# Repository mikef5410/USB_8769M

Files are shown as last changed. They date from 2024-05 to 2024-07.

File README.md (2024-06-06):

## USB_8769M 

USB control of Keysight 50GHz SP6T.

Related projects: [my USB Dual SPDT project](https://github.com/mikef5410/USB_SPDT)  and  [the software for these projects](https://github.com/mikef5410/USB_Attenuator_Switch_Stacklight)

# Project setup

The software is included here as a git submodule. After cloning, do a
`git submodule init` followed by `git submodule update --recursive`

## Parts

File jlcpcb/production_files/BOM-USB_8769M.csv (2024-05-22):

Comment | Designator | Footprint | LCSC
4.7u | C17,C5,C7 | C_0402_1005Metric_Pad0.74x0.62mm_HandSolder | C106859
LP2985-3.3 | U2 | SOT-23-5 | C109382
Conn_02x07_Odd_Even | J3 | IDC-Header_2x07_P2.54mm_Vertical | C11215
MMZ1608Y102B | FB1 | C_0603_1608Metric_Pad1.08x0.95mm_HandSolder | C114771
13.3k | R5 | R_0402_1005Metric_Pad0.72x0.64mm_HandSolder | C122547
22uF | C19 | C_1206_3216Metric_Pad1.33x1.80mm_HandSolder | C12891
USB_B_Micro | J1 | USB_Micro-B_Amphenol_10118193-0001LF_Horizontal | C132562
1u | C1,C14,C20,C21,C4 | C_0603_1608Metric_Pad1.08x0.95mm_HandSolder | C15849
220p | C2 | C_0402_1005Metric_Pad0.74x0.62mm_HandSolder | C1603
30pF | C15,C16 | C_0402_1005Metric_Pad0.74x0.62mm_HandSolder | C1658
10u | L1 | L_Changjiang_FNR4030S | C167879
0 | R1,R6 | R_0402_1005Metric_Pad0.72x0.64mm_HandSolder | C17168
4.7u | C3 | C_0805_2012Metric_Pad1.18x1.45mm_HandSolder | C1779
100 | R11,R13,R14,R15,R16,R9 | R_0402_1005Metric_Pad0.72x0.64mm_HandSolder | C25076
10k | R10,R12,R7,R8 | R_0402_1005Metric_Pad0.72x0.64mm_HandSolder | C25744
118k | R4 | R_0402_1005Metric_Pad0.72x0.64mm_HandSolder | C25748
SW_Push | SW1,SW2 | SW_Tactile_SPST_NO_Straight_CK_PTS636Sx25SMTRLFS | C2800965
PRTR5V0U2X | D2 | SOT-143 | C2827688
LM27313XMF | U1 | SOT-23-5 | C341750
GRN | D4 | LED_0603_1608Metric_Pad1.05x0.95mm_HandSolder | C434423
93LC66AT-IOT | U4 | SOT-23-6 | C511344
0.1u | C10,C11,C12,C13,C18,C6,C8,C9 | C_0402_1005Metric_Pad0.74x0.62mm_HandSolder | C5142567
16M 20pF 3225 | Y1 | Crystal_SMD_3225-4Pin_3.2x2.5mm_HandSoldering | C524727
ULN2003ADR | U5,U6 | SOIC-16_4.55x10.3mm_P1.27mm | C7512
RED | D3,D5,D6,D7 | LED_0603_1608Metric_Pad1.05x0.95mm_HandSolder | C84263
SS34 | D1 | D_SMA | C8678
STM32F411RETx | U3 | LQFP-64_10x10mm_P0.5mm | C94355

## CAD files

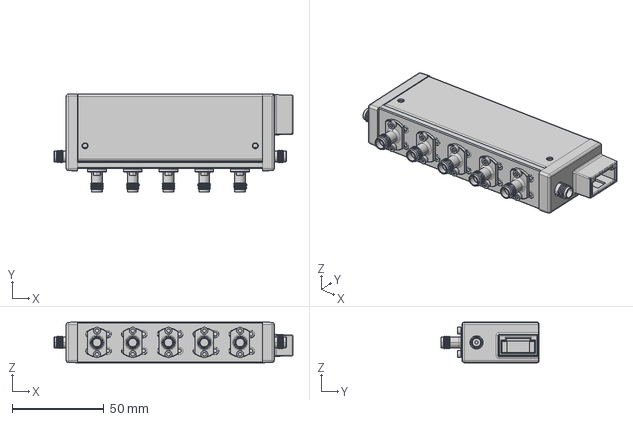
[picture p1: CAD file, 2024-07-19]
8769M.STP
130.2 x 53.6 x 22.3 mm

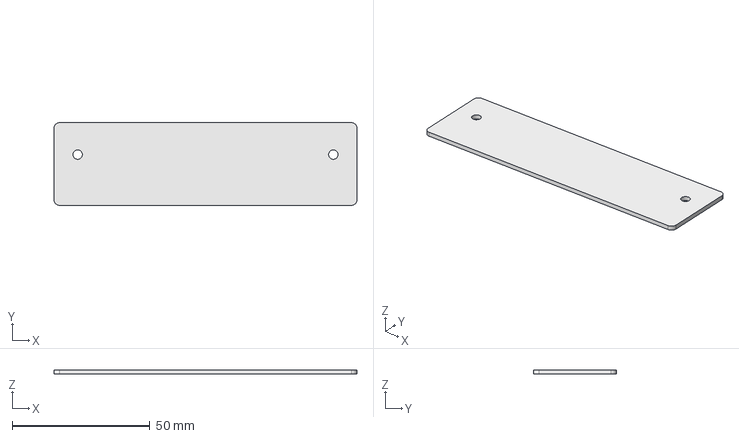
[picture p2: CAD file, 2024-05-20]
pcb_blank.FCStd
110.0 x 30.0 x 1.60 mm

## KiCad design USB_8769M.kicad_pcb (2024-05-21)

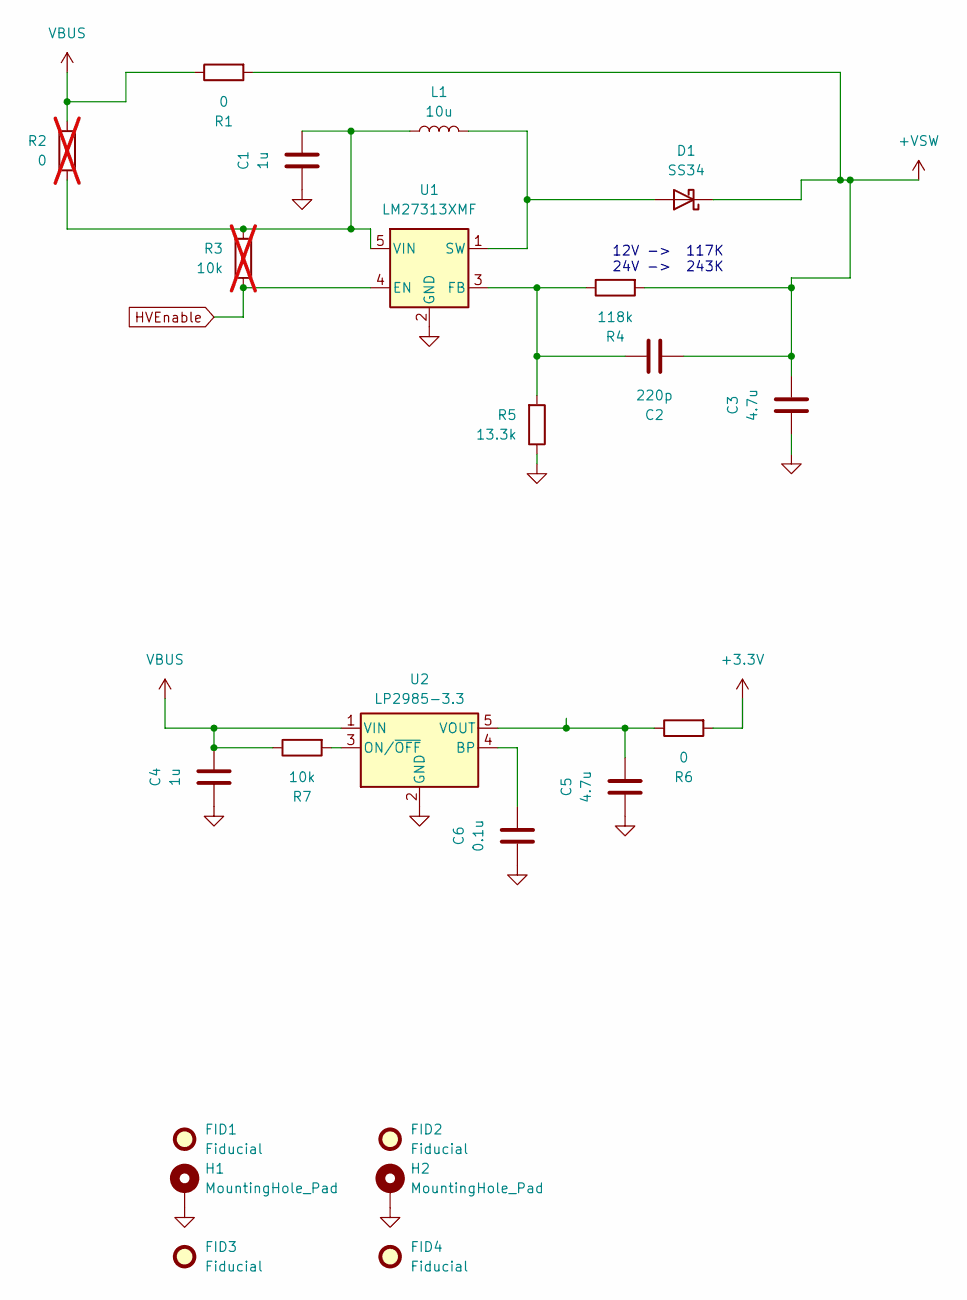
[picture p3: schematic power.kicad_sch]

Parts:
C1, C4: 1u; C_0603_1608Metric_Pad1.08x0.95mm_HandSolder; LCSC C15849
C2: 220p; C_0402_1005Metric_Pad0.74x0.62mm_HandSolder; LCSC C1603
C3: 4.7u; C_0805_2012Metric_Pad1.18x1.45mm_HandSolder; LCSC C1779
C5: 4.7u; C_0402_1005Metric_Pad0.74x0.62mm_HandSolder; LCSC C106859
C6: 0.1u; C_0402_1005Metric_Pad0.74x0.62mm_HandSolder; LCSC C5142567
D1: SS34; D_SMA; LCSC C8678
FID1, FID2, FID3, FID4: Fiducial; Fiducial_1mm_Mask3mm
H1, H2: MountingHole_Pad; MountingHole_3.2mm_M3_DIN965_Pad_TopBottom
L1: 10u; L_Changjiang_FNR4030S; LCSC C167879
R1, R6: 0; R_0402_1005Metric_Pad0.72x0.64mm_HandSolder; LCSC C17168
R2: 0; R_0402_1005Metric_Pad0.72x0.64mm_HandSolder; LCSC C17168; not fitted
R3: 10k; R_0402_1005Metric_Pad0.72x0.64mm_HandSolder; LCSC C25744; not fitted
R4: 118k; R_0402_1005Metric_Pad0.72x0.64mm_HandSolder; LCSC C25748
R5: 13.3k; R_0402_1005Metric_Pad0.72x0.64mm_HandSolder; LCSC C122547
R7: 10k; R_0402_1005Metric_Pad0.72x0.64mm_HandSolder; LCSC C25744
U1: LM27313XMF; SOT-23-5; LCSC C341750
U2: LP2985-3.3; SOT-23-5; LCSC C109382

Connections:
+3.3V: R6.2; also elsewhere on the board
+VSW: C2.1, C3.2, D1.1 (K), R1.2, R4.2; also elsewhere on the board
GND: C1.1, C3.1, C4.1, C5.1, C6.1, H1.1, H2.1, R5.1, U1.2 (GND), U2.2 (GND); also elsewhere on the board
HVEnable: R3.1, U1.4 (EN); also elsewhere on the board
unnamed: D1.2 (A), L1.2, U1.1 (SW)
unnamed: C2.2, R4.1, R5.2, U1.3 (FB)
unnamed: C1.2, L1.1, R2.1, R3.2, U1.5 (VIN)
unnamed: C6.2, U2.4 (BP)
unnamed: R7.2, U2.3 (ON/~OFF)
unnamed: C5.2, R6.1, U2.5 (VOUT)
VBUS: C4.2, R1.1, R2.2, R7.1, U2.1 (VIN); also elsewhere on the board

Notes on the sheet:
12V -> 117K 24V -> 243K

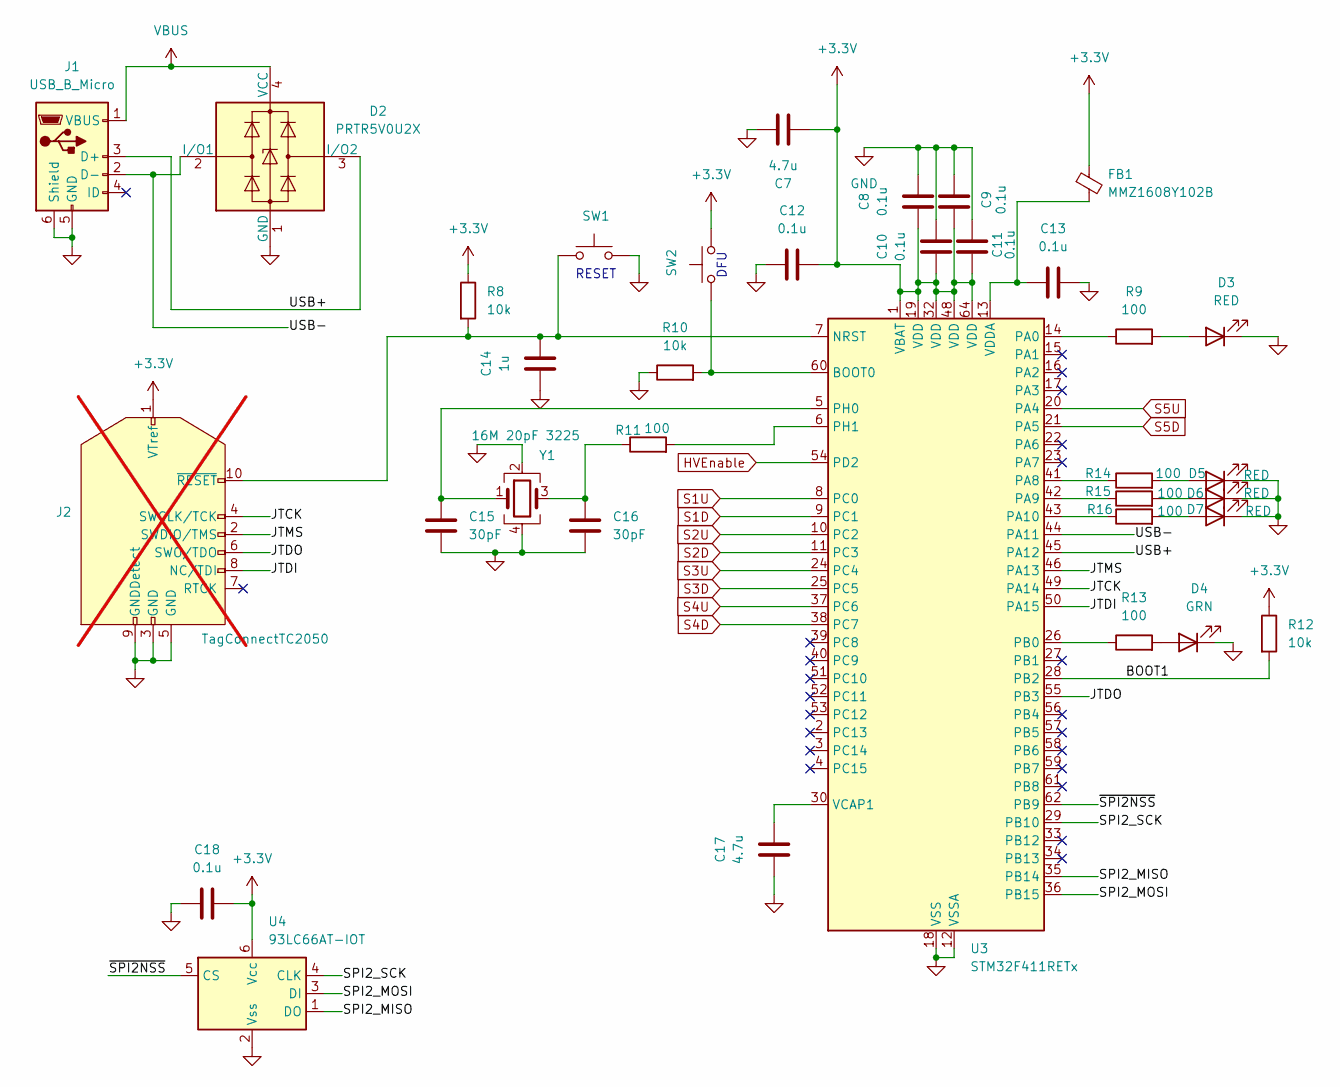
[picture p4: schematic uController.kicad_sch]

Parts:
C7, C17: 4.7u; C_0402_1005Metric_Pad0.74x0.62mm_HandSolder; LCSC C106859
C8, C9, C10, C11, C12, C13, C18: 0.1u; C_0402_1005Metric_Pad0.74x0.62mm_HandSolder; LCSC C5142567
C14: 1u; C_0603_1608Metric_Pad1.08x0.95mm_HandSolder; LCSC C15849
C15, C16: 30pF; C_0402_1005Metric_Pad0.74x0.62mm_HandSolder; LCSC C1658
D2: PRTR5V0U2X; SOT-143; LCSC C2827688
D3, D5, D6, D7: RED; LED_0603_1608Metric_Pad1.05x0.95mm_HandSolder; LCSC C84263
D4: GRN; LED_0603_1608Metric_Pad1.05x0.95mm_HandSolder; LCSC C434423
FB1: MMZ1608Y102B; C_0603_1608Metric_Pad1.08x0.95mm_HandSolder; LCSC C114771
J1: USB_B_Micro; USB_Micro-B_Amphenol_10118193-0001LF_Horizontal; LCSC C132562
J2: TagConnectTC2050; Tag-Connect_TC2050-IDC-FP_2x05_P1.27mm_Vertical; not fitted
R8, R10, R12: 10k; R_0402_1005Metric_Pad0.72x0.64mm_HandSolder; LCSC C25744
R9, R11, R13, R14, R15, R16: 100; R_0402_1005Metric_Pad0.72x0.64mm_HandSolder; LCSC C25076
SW1, SW2: SW_Push; SW_Tactile_SPST_NO_Straight_CK_PTS636Sx25SMTRLFS; LCSC C2800965
U3: STM32F411RETx; LQFP-64_10x10mm_P0.5mm; LCSC C94355
U4: 93LC66AT-IOT; SOT-23-6; LCSC C511344
Y1: 16M 20pF 3225; Crystal_SMD_3225-4Pin_3.2x2.5mm_HandSoldering; MPN 7U16000E20UCG; LCSC C524727

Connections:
+3.3V: C7.1, C8.1, C9.2, C10.1, C11.1, C12.2, C18.2, FB1.1, J2.1 (VTref), R8.1, R12.1, SW2.2, U3.1 (VBAT), U3.19 (VDD), U3.32 (VDD), U3.48 (VDD), U3.64 (VDD), U4.6 (Vcc); also elsewhere on the board
/uController/BOOT1: R12.2, U3.28 (PB2)
/uController/JTCK: J2.4 (SWCLK/TCK), U3.49 (PA14)
/uController/JTDI: J2.8 (NC/TDI), U3.50 (PA15)
/uController/JTDO: J2.6 (SWO/TDO), U3.55 (PB3)
/uController/JTMS: J2.2 (SWDIO/TMS), U3.46 (PA13)
/uController/SPI2_MISO: U3.35 (PB14), U4.1 (DO)
/uController/SPI2_MOSI: U3.36 (PB15), U4.3 (DI)
/uController/SPI2_SCK: U3.29 (PB10), U4.4 (CLK)
/uController/USB+: D2.3 (I/O2), J1.3 (D+), U3.45 (PA12)
/uController/USB-: D2.2 (I/O1), J1.2 (D-), U3.44 (PA11)
/uController/~SPI2NSS: U3.62 (PB9), U4.5 (CS)
GND: C7.2, C8.2, C9.1, C10.2, C11.2, C12.1, C13.2, C14.1, C15.2, C16.2, C17.1, C18.1, D2.1 (GND), D3.1 (K), D4.1 (K), D5.1 (K), D6.1 (K), D7.1 (K), J1.5 (GND), J1.6 (Shield), J2.3 (GND), J2.5 (GND), J2.9 (GNDDetect), R10.1, SW1.2, U3.12 (VSSA), U3.18 (VSS), U3.31 (VSS), U3.47 (VSS), U3.63 (VSS), U4.2 (Vss), Y1.2, Y1.4; also elsewhere on the board
HVEnable: U3.54 (PD2); also elsewhere on the board
unnamed: C16.1, R11.1, Y1.3
unnamed: D3.2 (A), R9.2
unnamed: D4.2 (A), R13.2
unnamed: D5.2 (A), R14.2
unnamed: D6.2 (A), R15.2
unnamed: D7.2 (A), R16.2
unnamed: C14.2, J2.10 (~RESET), R8.2, SW1.1, U3.7 (NRST)
unnamed: R10.2, SW2.1, U3.60 (BOOT0)
unnamed: R9.1, U3.14 (PA0)
unnamed: R14.1, U3.41 (PA8)
unnamed: R15.1, U3.42 (PA9)
unnamed: R16.1, U3.43 (PA10)
unnamed: R13.1, U3.26 (PB0)
unnamed: C15.1, U3.5 (PH0), Y1.1
unnamed: R11.2, U3.6 (PH1)
unnamed: C17.2, U3.30 (VCAP1)
unnamed: C13.1, FB1.2, U3.13 (VDDA)
S1D: U3.9 (PC1); also elsewhere on the board
S1U: U3.8 (PC0); also elsewhere on the board
S2D: U3.11 (PC3); also elsewhere on the board
S2U: U3.10 (PC2); also elsewhere on the board
S3D: U3.25 (PC5); also elsewhere on the board
S3U: U3.24 (PC4); also elsewhere on the board
S4D: U3.38 (PC7); also elsewhere on the board
S4U: U3.37 (PC6); also elsewhere on the board
S5D: U3.21 (PA5); also elsewhere on the board
S5U: U3.20 (PA4); also elsewhere on the board
VBUS: D2.4 (VCC), J1.1 (VBUS); also elsewhere on the board

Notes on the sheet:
RESET
DFU

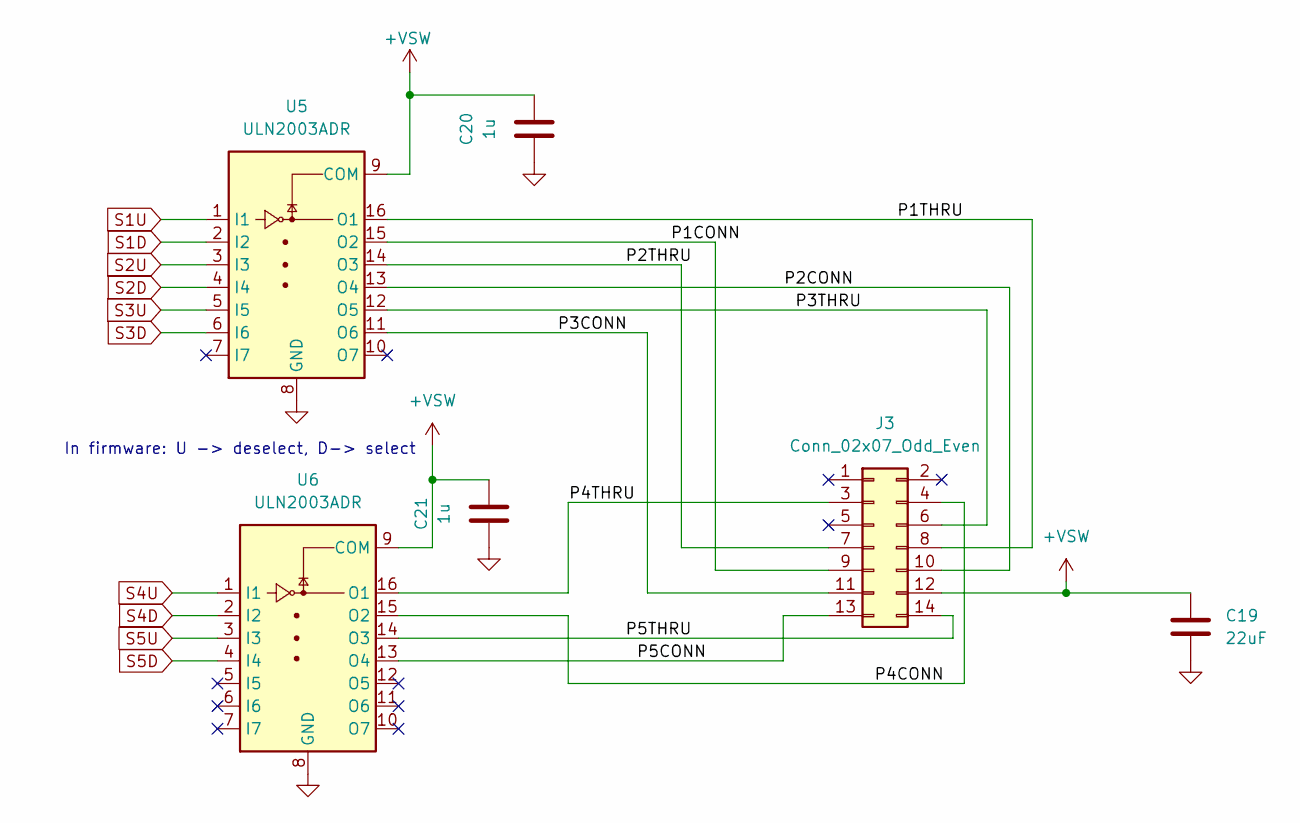
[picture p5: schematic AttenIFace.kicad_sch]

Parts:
C19: 22uF; C_1206_3216Metric_Pad1.33x1.80mm_HandSolder; LCSC C12891
C20, C21: 1u; C_0603_1608Metric_Pad1.08x0.95mm_HandSolder; LCSC C15849
J3: Conn_02x07_Odd_Even; IDC-Header_2x07_P2.54mm_Vertical; LCSC C11215
U5, U6: ULN2003ADR; SOIC-16_4.55x10.3mm_P1.27mm; LCSC C7512

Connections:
+VSW: C19.1, C20.2, C21.2, J3.12, U5.9 (COM), U6.9 (COM); also elsewhere on the board
/AttenIFace/P1CONN: J3.9, U5.15 (O2)
/AttenIFace/P1THRU: J3.8, U5.16 (O1)
/AttenIFace/P2CONN: J3.10, U5.13 (O4)
/AttenIFace/P2THRU: J3.7, U5.14 (O3)
/AttenIFace/P3CONN: J3.11, U5.11 (O6)
/AttenIFace/P3THRU: J3.6, U5.12 (O5)
/AttenIFace/P4CONN: J3.4, U6.15 (O2)
/AttenIFace/P4THRU: J3.3, U6.16 (O1)
/AttenIFace/P5CONN: J3.13, U6.13 (O4)
/AttenIFace/P5THRU: J3.14, U6.14 (O3)
GND: C19.2, C20.1, C21.1, U5.8 (GND), U6.8 (GND); also elsewhere on the board
S1D: U5.2 (I2); also elsewhere on the board
S1U: U5.1 (I1); also elsewhere on the board
S2D: U5.4 (I4); also elsewhere on the board
S2U: U5.3 (I3); also elsewhere on the board
S3D: U5.6 (I6); also elsewhere on the board
S3U: U5.5 (I5); also elsewhere on the board
S4D: U6.2 (I2); also elsewhere on the board
S4U: U6.1 (I1); also elsewhere on the board
S5D: U6.4 (I4); also elsewhere on the board
S5U: U6.3 (I3); also elsewhere on the board

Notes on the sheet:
In firmware: U -> deselect, D-> select

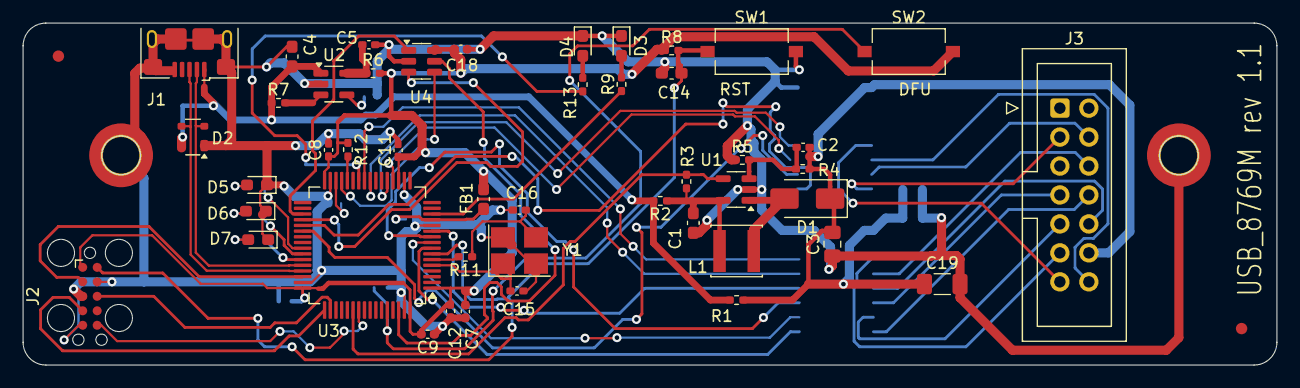
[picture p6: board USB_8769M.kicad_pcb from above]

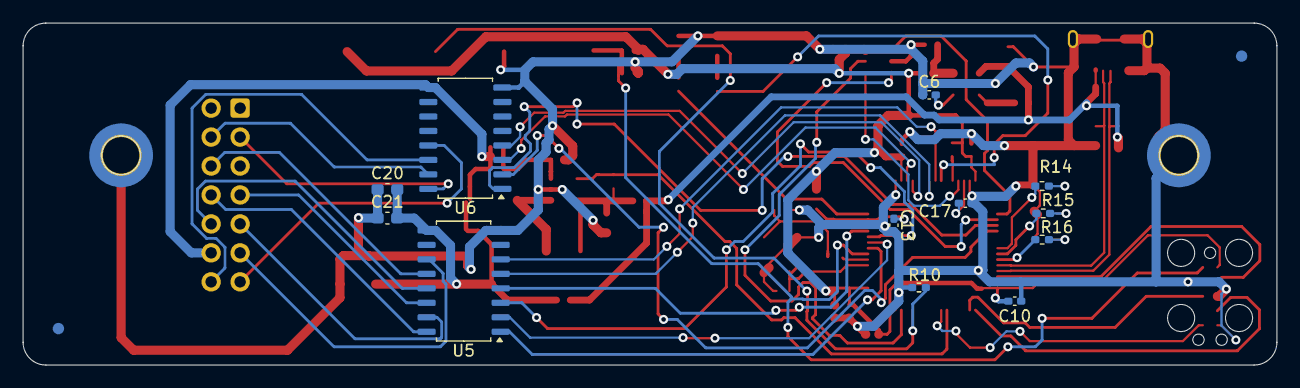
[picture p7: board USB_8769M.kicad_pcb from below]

Board: 2 copper layers, 110.0 x 30.0 mm, 64 parts (14 on the bottom side), 59 nets.

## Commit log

2024-05-20 Initial checkin
    [AttenIFace.kicad_sch, BOM-USB_8769M.csv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]
2024-05-21 C3,5,7,17 had LCSC changed to rev 1.1
    [USB_8769M.csv, USB_8769M.kicad_pcb, power.kicad_sch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]
2024-05-22 Update JLCPCB files. Part rotations will be incorrect, as I correct them on the website.
    [BOM-USB_8769M.csv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]
2024-06-06 Wrong LCSC part number for 3.3V regulator. BOOT1 needs to be held LOW not HIGH.
    [power.kicad_sch, uController.kicad_sch]
2024-07-19 Add step model for 8769M
    [8769M.STP]
